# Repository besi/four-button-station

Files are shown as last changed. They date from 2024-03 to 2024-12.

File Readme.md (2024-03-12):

# Four button station

Control four Relays.

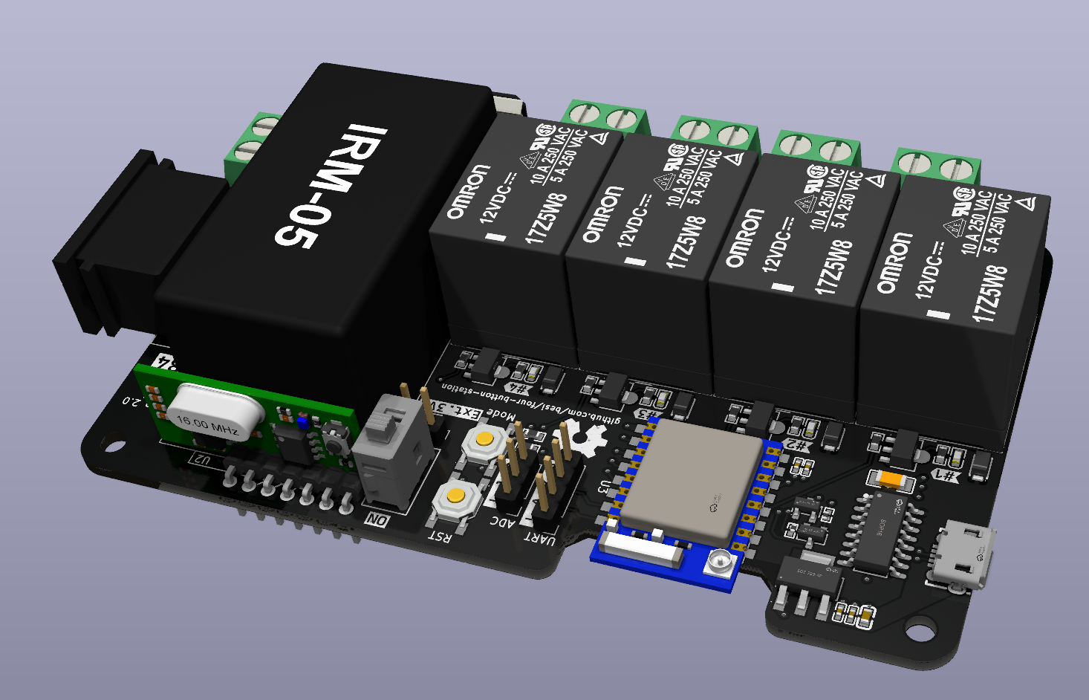
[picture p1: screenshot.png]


**WARNING**: This project uses 230V. Please be careful and use these resources at your own risk.

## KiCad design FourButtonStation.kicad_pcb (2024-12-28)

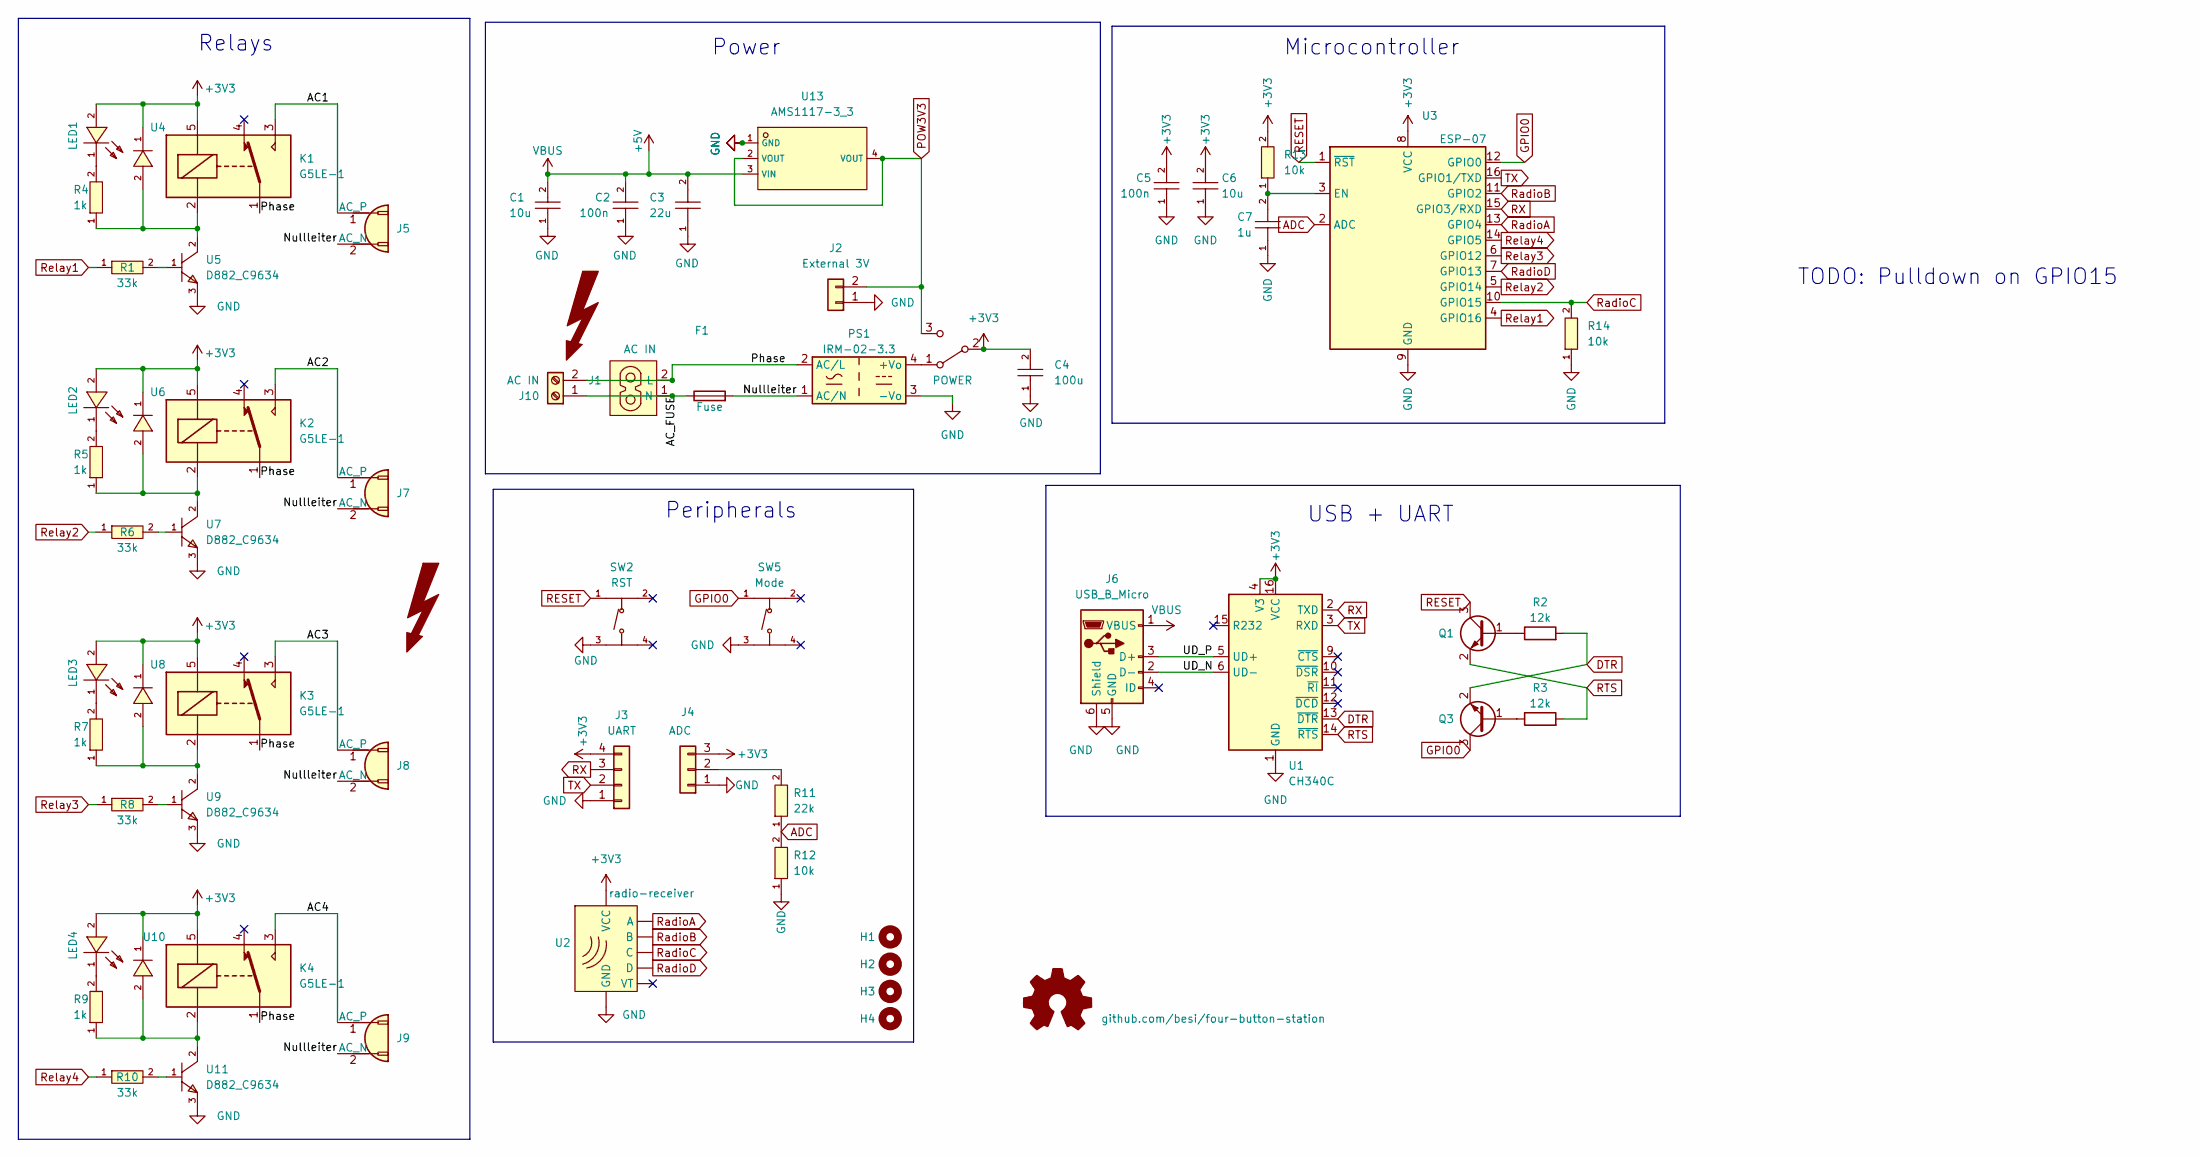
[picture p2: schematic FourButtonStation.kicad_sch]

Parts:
C1, C6: 10u; C0402; LCSC C15525
C2, C5: 100n; C0402; LCSC C1525
C3: 22u; C0603; LCSC C59461
C4: 100u; C1206; LCSC C15008
C7: 1u; C0603; LCSC C15849
F1: Fuse; Fuseholder_Cylinder-5x20mm_Schurter_0031_8201_Horizontal_Op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
H1, H2, H3, H4: MountingHole; MountingHole_3.2mm_M3
J1: AC IN; c8-inlet-old
J2: External 3V; PinHeader_1x02_P2.54mm_Vertical
J3: UART; PinHeader_1x04_P2.54mm_Vertical
J4: ADC; PinHeader_1x03_P2.54mm_Vertical
J5, J7, J8, J9: Conn_WallSocket; TerminalBlock_Phoenix_MKDS-1,5-2_1x02_P5.00mm_Horizontal
J6: USB_B_Micro; MICRO-USB-SMD_1050171001; LCSC C505111
J10: AC IN; TerminalBlock_Phoenix_MKDS-1,5-2_1x02_P5.00mm_Horizontal
K1, K2, K3, K4: G5LE-1; Relay_SPDT_Omron-G5LE-1
LED1, LED2, LED3, LED4: KT-0603R; LED0603-RD; LCSC C2286
Logo1: github.com/besi/four-button-station; OSHW-Symbol_6.7x6mm_SilkScreen
PS1: IRM-02-3.3; Converter_ACDC_MeanWell_IRM-05-xx_THT
Q1, Q3: MMBT3904; SOT-23-3_L2.9-W1.3-P1.90-LS2.4-BR; LCSC C20526
R1, R6, R8, R10: 33k; R0603; LCSC C4216
R2, R3: 12k; R0402; LCSC C25752
R4, R5, R7, R9: 1k; R0603; LCSC C4216
R11: 22k; R0603; LCSC C31850
R12, R13, R14: 10k; R0603; LCSC C25804
SW1: POWER; as12ap
SW2: RST; SW-SMD_4P-L5.1-W5.1-P3.70-LS6.5-TL-2; LCSC C318884
SW5: Mode; SW-SMD_4P-L5.1-W5.1-P3.70-LS6.5-TL-2; LCSC C318884
SYM1: SYM_Flash_XLarge
Sym3: SYM_Flash_XLarge
U1: CH340C; SOP-16_L10.0-W3.9-P1.27-LS6.0-BL; LCSC C7464026
U2: radio-receiver
U3: ESP-07; WIFIM-SMD_ESP-07; LCSC C82894
U4, U6, U8, U10: SM4007PL; SOD-123F_L2.8-W1.8-LS3.7-RD; LCSC C64898
U5, U7, U9, U11: D882_C9634; SOT-89-3_L4.5-W2.5-P1.50-LS4.2-BR; LCSC C9634
U13: AMS1117-3_3; SOT-223-3_L6.5-W3.4-P2.30-LS7.0-BR; LCSC C6186

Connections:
+3V3: C4.2, C5.2, C6.2, J3.4, J4.3, K1.5, K2.5, K3.5, K4.5, LED1.2 (A), LED2.2 (A), LED3.2 (A), LED4.2 (A), R13.2, SW1.2 (B), U1.4 (V3), U1.16 (VCC), U2.2 (VCC), U3.8 (VCC), U4.1 (C), U6.1 (C), U8.1 (C), U10.1 (C)
+5V: C1.2, C2.2, C3.2, J6.1 (VBUS), U13.3 (VIN)
/AC1: J5.1 (AC_P), K1.3
/AC2: J7.1 (AC_P), K2.3
/AC3: J8.1 (AC_P), K3.3
/AC4: J9.1 (AC_P), K4.3
/AC_FUSE: F1.1, J1.1 (N), J10.1
/Nullleiter: F1.2, J5.2 (AC_N), J7.2 (AC_N), J8.2 (AC_N), J9.2 (AC_N), PS1.1 (AC/N)
/Phase: J1.2 (L), J10.2, K1.1, K2.1, K3.1, K4.1, PS1.2 (AC/L)
/UD_N: J6.2 (D-), U1.6 (UD-)
/UD_P: J6.3 (D+), U1.5 (UD+)
ADC: R11.1, R12.2, U3.2 (ADC)
DTR: Q3.2 (E), R2.2, U1.13 (~DTR)
GND: C1.1, C2.1, C3.1, C4.1, C5.1, C6.1, C7.1, J2.1, J3.1, J4.1, J6.5 (GND), J6.6 (Shield), PS1.3 (-Vo), R12.1, R14.1, SW2.3 (C), SW5.3 (C), U1.1 (GND), U2.1 (GND), U3.9 (GND), U5.3 (E), U7.3 (E), U9.3 (E), U11.3 (E), U13.1 (GND)
GPIO0: Q3.3 (C), SW5.1 (A), U3.12 (GPIO0)
unnamed: J4.2, R11.2
unnamed: LED1.1 (K), R4.2
unnamed: LED2.1 (K), R5.2
unnamed: LED3.1 (K), R7.2
unnamed: LED4.1 (K), R9.2
unnamed: PS1.4 (+Vo), SW1.1 (A)
unnamed: Q1.1 (B), R2.1
unnamed: Q3.1 (B), R3.1
unnamed: C7.2, R13.1, U3.3 (EN)
unnamed: K1.2, R4.1, U4.2 (A), U5.2 (C)
unnamed: R1.2, U5.1 (B)
unnamed: K2.2, R5.1, U6.2 (A), U7.2 (C)
unnamed: R6.2, U7.1 (B)
unnamed: K3.2, R7.1, U8.2 (A), U9.2 (C)
unnamed: R8.2, U9.1 (B)
unnamed: K4.2, R9.1, U10.2 (A), U11.2 (C)
unnamed: R10.2, U11.1 (B)
POW3V3: J2.2, SW1.3 (C), U13.2 (VOUT), U13.4 (VOUT)
RESET: Q1.3 (C), SW2.1 (A), U3.1 (~RST)
RTS: Q1.2 (E), R3.2, U1.14 (~RTS)
RX: J3.3, U1.2 (TXD), U3.15 (GPIO3/RXD)
RadioA: U2.6 (A), U3.13 (GPIO4)
RadioB: U2.5 (B), U3.11 (GPIO2)
RadioC: R14.2, U2.4 (C), U3.10 (GPIO15)
RadioD: U2.3 (D), U3.7 (GPIO13)
Relay1: R1.1, U3.4 (GPIO16)
Relay2: R6.1, U3.5 (GPIO14)
Relay3: R8.1, U3.6 (GPIO12)
Relay4: R10.1, U3.14 (GPIO5)
TX: J3.2, U1.3 (RXD), U3.16 (GPIO1/TXD)

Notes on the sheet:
Relays
Microcontroller
Power
USB + UART
Peripherals
TODO: Pulldown on GPIO15

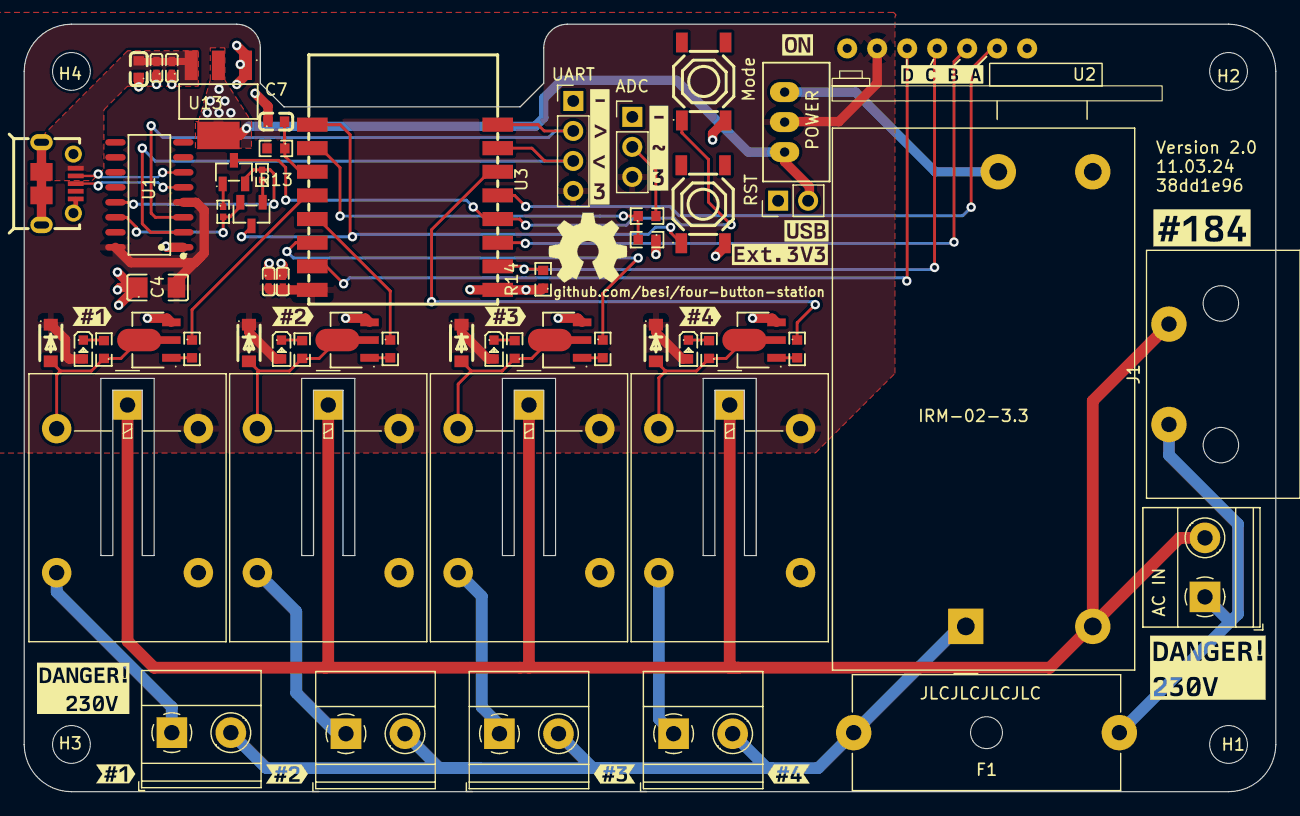
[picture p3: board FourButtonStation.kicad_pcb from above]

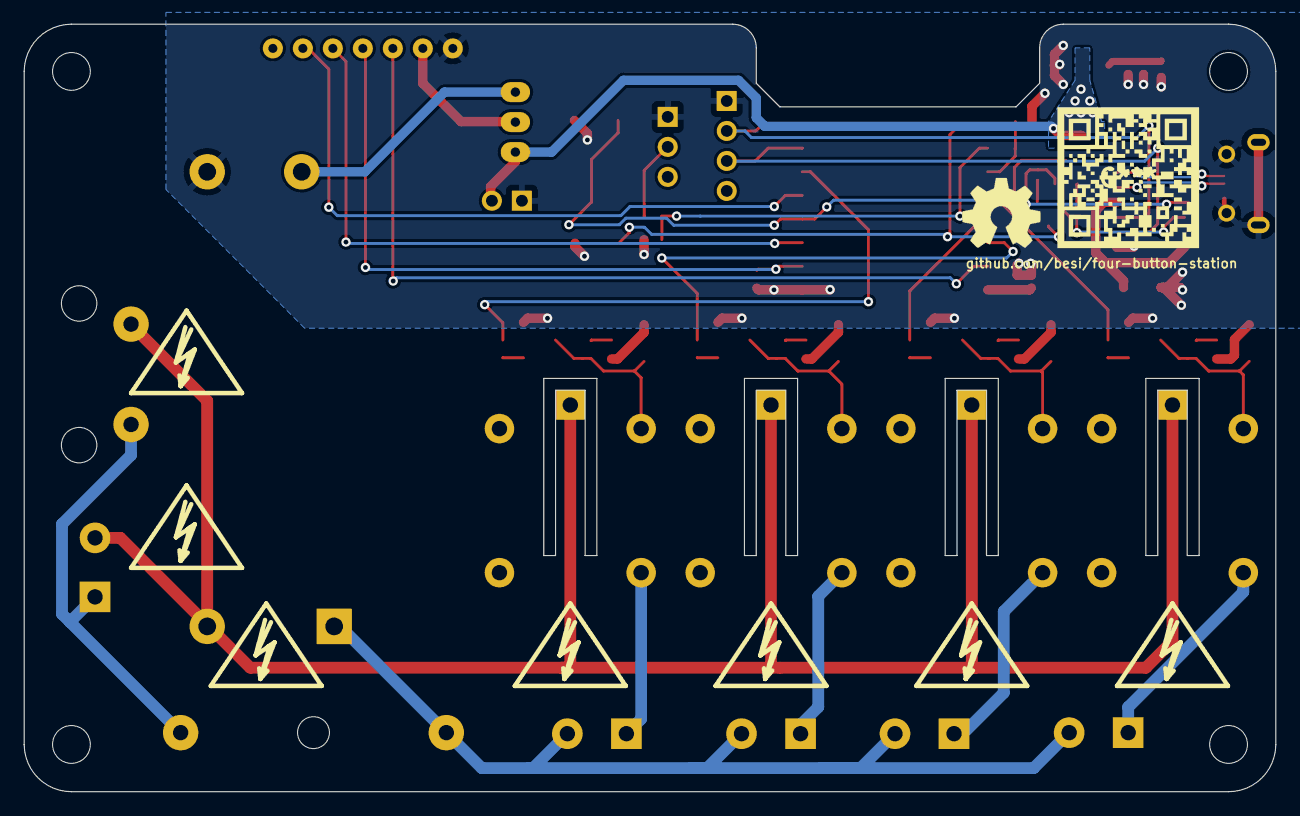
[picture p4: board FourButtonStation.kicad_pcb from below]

Board: 2 copper layers, 106.0 x 65.0 mm, 88 parts (8 on the bottom side), 45 nets.

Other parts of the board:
SYM1#2, SYM1#3, SYM1#4, SYM1#5, SYM1#6, SYM1#7: SYM_Flash_XLarge; Symbol_HighVoltage_Type2_CopperTop_VerySmall
Sym2: github.com/besi/four-button-station; OSHW-Symbol_6.7x6mm_SilkScreen
kibuzzard-65EDF7BF: G***; kibuzzard-65EDF7BF
kibuzzard-65EDF79E: G***; kibuzzard-65EDF79E
kibuzzard-65EE27C8: G***; kibuzzard-65EE27C8
kibuzzard-65EE27E0: G***; kibuzzard-65EE27E0
kibuzzard-65EE35B8: G***; kibuzzard-65EE35B8
kibuzzard-65EE261E: G***; kibuzzard-65EE261E
kibuzzard-65EE278E: G***; kibuzzard-65EE278E
kibuzzard-65EE298C: G***; kibuzzard-65EE298C
kibuzzard-65EE2541: G***; kibuzzard-65EE2541
kibuzzard-65EE2549, kibuzzard-65EE2549#2: G***; kibuzzard-65EE2549
kibuzzard-65EE2550, kibuzzard-65EE2550#2: G***; kibuzzard-65EE2550
kibuzzard-65EE2558: G***; kibuzzard-65EE2558
kibuzzard-65EE2681: G***; kibuzzard-65EE2681
kibuzzard-65EE2746: G***; kibuzzard-65EE2746
kibuzzard-65F05324: G***; kibuzzard-65F05324

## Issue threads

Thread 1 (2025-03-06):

Insufficient clearance between 230V phase and neutral

KubaO, 2025-03-06:
The clearance between 230V L/N must be 4mm. Currently it's 1mm.

I'll take care of that.

KubaO, 2025-03-06:
See https://github.com/KubaO/four-button-station/tree/fixes

I'm not sure what's going on with the two overlapping IEC inlets. They seem to be versions for old/new enclosure. I have left them unchanged.

besi, 2025-03-07:
This allows me to use either of them. Maybe it makes semse to choose one or put them sode by side. The idea was to have options since I might be using the boards in different scenarios.

> are subscribed to this thread.

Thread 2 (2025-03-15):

Flashing not possible when the radio receiver is plugged in

besi, 2025-03-15:

besi, 2025-03-15:
D3 seems to make trouble which corresponds to which is pulled to GND
GPIO0 could be used instead in order to use all inputs or a relay could be sacrificed.

besi, 2025-03-15:
```python

import machine
import time
radio_b = machine.Pin(2,machine.Pin.IN)
radio_a = machine.Pin(4,machine.Pin.IN)
radio_c = machine.Pin(15,machine.Pin.IN)
radio_d = machine.Pin(13,machine.Pin.IN)

while True:
    if radio_a() == True: print("A pressed"); time.sleep(0.5)
    if radio_b() == True: print("B pressed"); time.sleep(0.5)
    if radio_c() == True: print("C pressed"); time.sleep(0.5)
    if radio_d() == True: print("D pressed"); time.sleep(0.5)

# C pressed
# D pressed
# A pressed
```

All but **Button B** seem to work.

## Mapping of the pins

The mapping is reversed.

D0 = D
D1 = C
D2 = B
D3 = A

D2 seems to make trouble which corresponds to which is pulled to GND

besi, 2025-03-15:
A workaround is to cut the trace to GPIO2 and instead use the ADC for the "B - Button"

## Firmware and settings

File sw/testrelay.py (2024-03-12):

import machine
import time
rec1 = machine.Pin(2,machine.Pin.IN)
rec2 = machine.Pin(4,machine.Pin.IN)
rec3 = machine.Pin(9,machine.Pin.IN)
rec4 = machine.Pin(10,machine.Pin.IN)

rel1 = machine.Pin(16,machine.Pin.OUT)
rel2 = machine.Pin(14,machine.Pin.OUT)
rel3 = machine.Pin(12,machine.Pin.OUT)
rel4 = machine.Pin(5,machine.Pin.OUT)

while True:
    rel1.on()
    time.sleep(2)
    rel1.off()
    time.sleep(2)
    

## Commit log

2024-03-08 Schematic and routing
    [FourButtonStation.kicad_pcb, FourButtonStation.kicad_sch]
2024-03-10 Prepare for production
    [FourButtonStation.kicad_pcb, FourButtonStation.kicad_sch]
2024-03-11 Final tweaks
    [FourButtonStation.kicad_pcb]
2024-03-11 Production files for 2.0
    [FourButtonStation.kicad_pcb, FourButtonStation.kicad_sch]
2024-03-11 Thermal conductivity for the AMS117
    [FourButtonStation.kicad_pcb]
2024-03-11 Prepare release 2.0
    [FourButtonStation.kicad_pcb, FourButtonStation.kicad_sch]
2024-03-12 Update documentation and silkscreen
    [FourButtonStation.kicad_pcb]
2024-03-12 Update version
    [FourButtonStation.kicad_pcb, FourButtonStation.kicad_sch]
2024-03-12 Add 10k pull up for enabling the esp
    [FourButtonStation.kicad_pcb, FourButtonStation.kicad_sch]
2024-12-28 Update schematic
    [FourButtonStation.kicad_pcb, FourButtonStation.kicad_sch]
